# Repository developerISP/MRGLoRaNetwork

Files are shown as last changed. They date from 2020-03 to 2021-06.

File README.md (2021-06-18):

# Col Margherita LoRa Project (ROSY: Remote Observatory SYstem)
This is the repository for the school-work project between the Istitute of Polar Science ISP-CNR of Venice and the ITIS Max Planck of Villorba (TV)

# Who
The wonderful people involved in the ROSY project are all students, as they will never stop to learn! 

The young team in electronics, computer science, power management and telecommunications that built up the work is:
Nicolò Baseggio,
Davide Dal Bo,
Andrea De Marchi,
Michele Ferrarese,
Massimiliano Granziol,
Marco Martini,
Silvia Mondin,
Federico Peruzzo,
Roberto Pomiato,
Nicolò Rasera,
Nicola Voltarel

The group is trained and motivated by selfless and great teachers:
Alessandro Rocco Monteduro,
Monica Disarò,
Eugenio Rossi,
Giorgio Damian

The project is coordinated by enthusiastic researchers:
Federico Dallo,
Daniele Zannoni,
Fabrizio De Blasi,
Jacopo Gabrieli,
Carlo Barbante

# When
The project started in January 2020, continued throughout the tough Covid-19 pandemic thanks to the great motivation of the students and is on its way to be completed during the spring 2021. We were able to continue the development of hardware and software thanks to the distance learing (DAD) and tele-work. We have met at the ITIS Max Planck laboratories to build up the instrumentations and to perform several test, such as measuring the power comsumption and telecommunication capabilieties of the instruments. We were hosted at the Ca' Foscari University Campus in Via Torino and at the National Research Council (CNR) Col Margherita Observatory in the Belluno province.

# How

# Why

# Network
Files related to the acquisition, communication and ... are organized in the "network" directory. 

# Meteorology
Files for the analysis of meteorological variables are organized in the "meteorology" directory.
```
.
└── meteorology
    ├── data
    │   ├── MRG_2017_2018.csv
    │   └── P_Valles_2010_2020.csv
    ├── main.R
    └── outputs
        ├── MRGatmosphericpressuretypicalyear.csv
        ├── MRGatmosphericpressuretypicalyear.png
        ├── MRGrelativehumiditytypicalyear.csv
        ├── MRGrelativehumiditytypicalyear.png
        ├── MRGsolarradiationtypicalyear.csv
        ├── MRGsolarradiationtypicalyear.png
        ├── MRGtemperaturetypicalyear.csv
        ├── MRGtemperaturetypicalyear.png
        ├── MRGwinddirectiontypicalyear_autunno.png
        ├── MRGwinddirectiontypicalyear.csv
        ├── MRGwinddirectiontypicalyear_estate.png
        ├── MRGwinddirectiontypicalyear_inverno.png
        ├── MRGwinddirectiontypicalyear_primavera.png
        ├── MRGwindspeedtypicalyear.csv
        └── MRGwindspeedtypicalyear.png

3 directories, 18 files
```

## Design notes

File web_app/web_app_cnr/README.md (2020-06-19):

[doc]: https://dart.dev/guides/language/effective-dart/documentation

# Versione 1.0.1

## Modifiche

* è stato modificato leggermente il layout della pagina,
spostando la [timeBar](#timebar) in un "popup" accessibile cliccando il pulsante in alto a destra (con questa icona: > <)

* è stata abbozzata la documentazione dei file presenti in `MRGLoRaNetwork\web_app\web_app_cnr\lib`

## Link

vedi [Effective Dart: Documentation][doc] per maggiori informazioni sulla documentazione di dart

# Versione 1.0.2

## Modifiche

* tutti i grafici sono stati resi indipendenti l'uno dall'altro, dal punto di vista dei valori, mentre le date corrispondenti a questi sono comuni a tutti i grafici.</br>
    > ora la [timeBar](#timebar) modifica l'intervallo su tutti quanti i grafici

* sono stati completati gli `indicatori del vento e dell'umidità` *( icona e animazione)*

</br>

---

## Vocabolario

### timeBar

> Barra per la modifica dell'intervallo di tempo, visibile nei vari grafici della home page

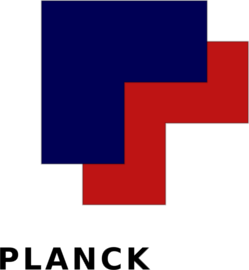
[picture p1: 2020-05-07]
web_app/web_app_cnr/images/ITIS-maxPlanck.png

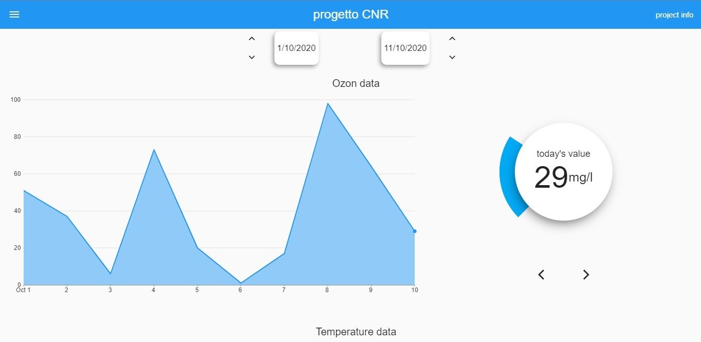
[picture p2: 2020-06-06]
web_app/web_app_cnr/images/web_app.jpg

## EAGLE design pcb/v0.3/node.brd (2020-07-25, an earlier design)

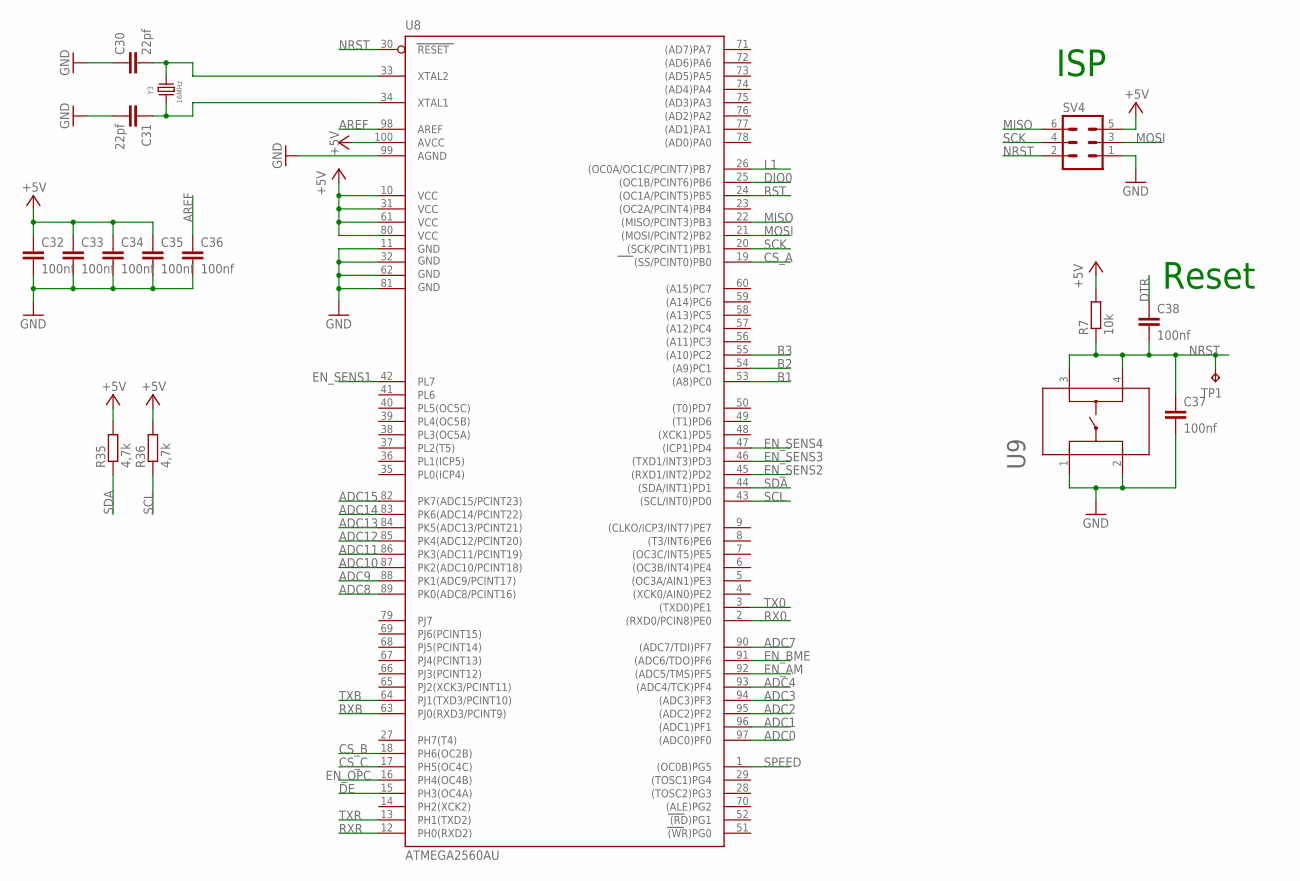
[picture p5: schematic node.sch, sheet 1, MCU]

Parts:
C30, C31: 22pf; C0603
C32, C33, C34, C35, C36, C37, C38: 100nf; C0805
R7: 10k; R0805
R35, R36: 4,7k; R0603
SV4: MA03-2
TP1: TPTP13R; TP13R
U8: ATMEGA2560AU; TQFP100
U9: 1-1825910-0; SWITCH_1-1825910-0
Y3: 16MHz; WE-XTAL_HC49/4H

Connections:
+5V: C32.1, C33.1, C34.1, C35.1, R7.2, R35.2, R36.2, SV4.5, U8.10 (VCC), U8.31 (VCC1), U8.61 (VCC2), U8.80 (VCC3), U8.100 (AVCC); also elsewhere on the board
ADC0: U8.97 ((ADC0)PF0)
ADC1: U8.96 ((ADC1)PF1); also elsewhere on the board
ADC2: U8.95 ((ADC2)PF2); also elsewhere on the board
ADC3: U8.94 ((ADC3)PF3); also elsewhere on the board
ADC4: U8.93 ((ADC4/TCK)PF4); also elsewhere on the board
ADC7: U8.90 ((ADC7/TDI)PF7); also elsewhere on the board
ADC8: U8.89 (PK0(ADC8/PCINT16))
ADC9: U8.88 (PK1(ADC9/PCINT17))
ADC10: U8.87 (PK2(ADC10/PCINT18))
ADC11: U8.86 (PK3(ADC11/PCINT19))
ADC12: U8.85 (PK4(ADC12/PCINT20))
ADC13: U8.84 (PK5(ADC13/PCINT21))
ADC14: U8.83 (PK6(ADC14/PCINT22))
ADC15: U8.82 (PK7(ADC15/PCINT23))
AREF: C36.1, U8.98 (AREF)
B1: U8.53 ((A8)PC0); also elsewhere on the board
B2: U8.54 ((A9)PC1); also elsewhere on the board
B3: U8.55 ((A10)PC2)
CS_A: U8.19 ((SS/PCINT0)PB0); also elsewhere on the board
CS_B: U8.18 (PH6(OC2B)); also elsewhere on the board
CS_C: U8.17 (PH5(OC4C)); also elsewhere on the board
DE: U8.15 (PH3(OC4A)); also elsewhere on the board
DIO0: U8.25 ((OC1B/PCINT6)PB6); also elsewhere on the board
DTR: C38.1; also elsewhere on the board
EN_AM: U8.92 ((ADC5/TMS)PF5); also elsewhere on the board
EN_BME: U8.91 ((ADC6/TDO)PF6); also elsewhere on the board
EN_OPC: U8.16 (PH4(OC4B)); also elsewhere on the board
EN_SENS1: U8.42 (PL7); also elsewhere on the board
EN_SENS2: U8.45 ((RXD1/INT2)PD2); also elsewhere on the board
EN_SENS3: U8.46 ((TXD1/INT3)PD3); also elsewhere on the board
EN_SENS4: U8.47 ((ICP1)PD4); also elsewhere on the board
GND: C30.1, C31.2, C32.2, C33.2, C34.2, C35.2, C36.2, C37.2, SV4.1, U8.11 (GND), U8.32 (GND1), U8.62 (GND2), U8.81 (GND3), U8.99 (AGND), U9.1, U9.2; also elsewhere on the board
L1: U8.26 ((OC0A/OC1C/PCINT7)PB7); also elsewhere on the board
MISO: SV4.6, U8.22 ((MISO/PCINT3)PB3); also elsewhere on the board
MOSI: SV4.3, U8.21 ((MOSI/PCINT2)PB2); also elsewhere on the board
unnamed: C30.2, U8.33 (XTAL2), Y3.2
unnamed: C31.1, U8.34 (XTAL1), Y3.1
NRST: C37.1, C38.2, R7.1, SV4.2, TP1.TP, U8.30 (RESET), U9.3, U9.4
RST: U8.24 ((OC1A/PCINT5)PB5); also elsewhere on the board
RX0: U8.2 ((RXD0/PCIN8)PE0); also elsewhere on the board
RXB: U8.63 (PJ0(RXD3/PCINT9)); also elsewhere on the board
RXR: U8.12 (PH0(RXD2)); also elsewhere on the board
SCK: SV4.4, U8.20 ((SCK/PCINT1)PB1); also elsewhere on the board
SCL: R36.1, U8.43 ((SCL/INT0)PD0); also elsewhere on the board
SDA: R35.1, U8.44 ((SDA/INT1)PD1); also elsewhere on the board
SPEED: U8.1 ((OC0B)PG5); also elsewhere on the board
TX0: U8.3 ((TXD0)PE1); also elsewhere on the board
TXB: U8.64 (PJ1(TXD3/PCINT10)); also elsewhere on the board
TXR: U8.13 (PH1(TXD2)); also elsewhere on the board

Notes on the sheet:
Reset
ISP

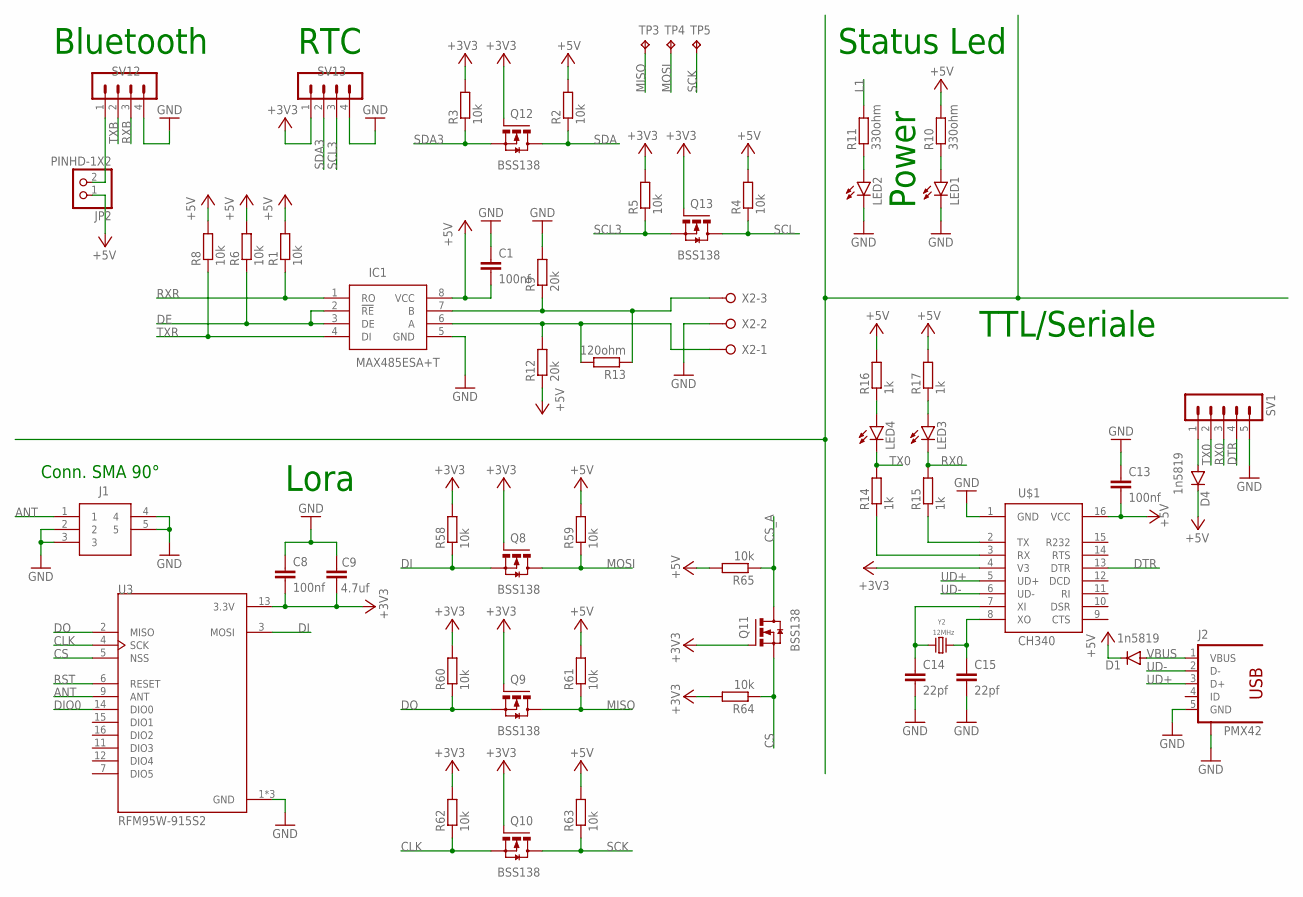
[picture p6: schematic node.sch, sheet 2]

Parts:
C1, C8, C13: 100nf; C0805
C9: 4.7uf; C1206K
C14, C15: 22pf; C0603
D1, D4: 1n5819; SOD123
IC1: MAX485ESA+T; SOIC127P600X175-8N
J1: 5-1814400-1; 518144001
J2: PMX42; PMX42_56579-0576
JP2: PINHD-1X2; 1X02
LED1, LED2, LED3, LED4: LEDSML0805; SML0805
Q8, Q9, Q10, Q11, Q12, Q13: BSS138; SOT23-3
R1, R2, R3, R4, R5, R6, R8, R58, R59, R60, R61, R62, R63, R64, R65: 10k; R0805
R9, R12: 20k; R0805
R10, R11: 330ohm; R0805
R13: 120ohm; R0805
R14, R15, R16, R17: 1k; R0805
SV1: MA05-1
SV12, SV13: MA04-1
TP3, TP4, TP5: TPTP13R; TP13R
U3: RFM95W-915S2; XCVR_RFM95W-915S2
U$1: CH340; SOIC16
X2: W237-3E
Y2: 12MHz; WE-XTAL_HC49/4H

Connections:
+3V3: C8.2, C9.1, Q8.1 (G), Q9.1 (G), Q10.1 (G), Q11.1 (G), Q12.1 (G), Q13.1 (G), R3.2, R5.2, R58.2, R60.2, R62.2, R64.2, SV13.1, U3.13 (3.3V), U$1.4 (V3); also elsewhere on the board
+5V: C1.2, C13.2, D1.C, D4.C, IC1.8 (VCC), JP2.1, R1.2, R2.2, R4.2, R6.2, R8.2, R10.2, R12.1, R16.2, R17.2, R59.2, R61.2, R63.2, R65.2, U$1.16 (VCC); also elsewhere on the board
ANT: J1.1, U3.9 (ANT)
CLK: Q10.2 (S), R62.1, U3.4 (SCK)
CS: Q11.2 (S), R64.1, U3.5 (NSS)
CS_A: Q11.3 (D), R65.1; also elsewhere on the board
DE: IC1.2 (!RE), IC1.3 (DE), R6.1; also elsewhere on the board
DI: Q8.2 (S), R58.1, U3.3 (MOSI)
DIO0: U3.14 (DIO0); also elsewhere on the board
DO: Q9.2 (S), R60.1, U3.2 (MISO)
DTR: SV1.4, U$1.13 (DTR); also elsewhere on the board
GND: C1.1, C8.1, C9.2, C13.1, C14.2, C15.2, IC1.5 (GND), J1.2, J1.3, J1.4, J1.5, J2.5 (GND), J2.S1 (S), J2.S2 (S), J2.S3 (S), J2.S4 (S), LED1.C, LED2.C, R9.2, SV1.5, SV12.4, SV13.4, U3.1 (GND), U3.8 (GND), U3.10 (GND), U$1.1 (GND), X2.2; also elsewhere on the board
L1: R11.2; also elsewhere on the board
MISO: Q9.3 (D), R61.1, TP3.TP; also elsewhere on the board
MOSI: Q8.3 (D), R59.1, TP4.TP; also elsewhere on the board
unnamed: JP2.2, SV12.1
unnamed: LED1.A, R10.1
unnamed: LED2.A, R11.1
unnamed: R15.1, U$1.2 (TX)
unnamed: R14.1, U$1.3 (RX)
unnamed: C15.1, U$1.8 (XO), Y2.1
unnamed: C14.1, U$1.7 (XI), Y2.2
unnamed: LED3.A, R17.1
unnamed: LED4.A, R16.1
unnamed: D4.A, SV1.1
unnamed: IC1.6 (A), R12.2, R13.2, X2.1
unnamed: IC1.7 (B), R9.1, R13.1, X2.3
RST: U3.6 (RESET); also elsewhere on the board
RX0: LED3.C, R15.2, SV1.3; also elsewhere on the board
RXB: SV12.3; also elsewhere on the board
RXR: IC1.1 (RO), R1.1; also elsewhere on the board
SCK: Q10.3 (D), R63.1, TP5.TP; also elsewhere on the board
SCL: Q13.3 (D), R4.1; also elsewhere on the board
SCL3: Q13.2 (S), R5.1, SV13.3
SDA: Q12.3 (D), R2.1; also elsewhere on the board
SDA3: Q12.2 (S), R3.1, SV13.2
TX0: LED4.C, R14.2, SV1.2; also elsewhere on the board
TXB: SV12.2; also elsewhere on the board
TXR: IC1.4 (DI), R8.1; also elsewhere on the board
UD+: J2.3 (D+), U$1.5 (UD+)
UD-: J2.2 (D-), U$1.6 (UD-)
VBUS: D1.A, J2.1 (VBUS)

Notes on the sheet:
Power
Lora
Conn. SMA 90°
TTL/Seriale
Status Led
Bluetooth
RTC

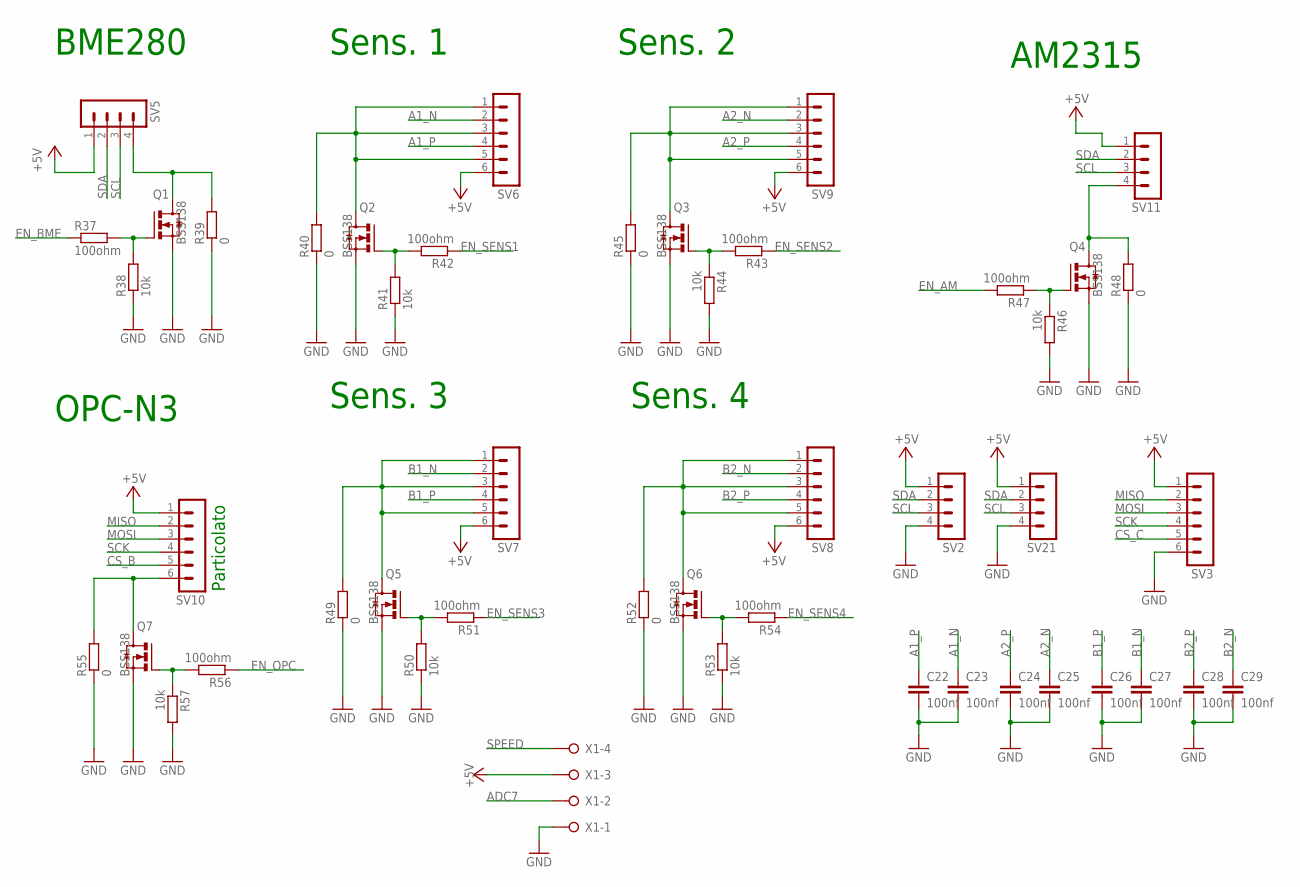
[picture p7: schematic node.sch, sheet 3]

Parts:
C22, C23, C24, C25, C26, C27, C28, C29: 100nf; C0805
Q1, Q2, Q3, Q4, Q5, Q6, Q7: BSS138; SOT23-3
R37, R42, R43, R47, R51, R54, R56: 100ohm; R0805W
R38, R41, R44, R46, R50, R53, R57: 10k; R0805W
R39, R40, R45, R48, R49, R52, R55: 0; R0603
SV2, SV5, SV11, SV21: MA04-1
SV3, SV6, SV7, SV8, SV9, SV10: MA06-1
X1: W237-04P; W237-4P

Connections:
+5V: SV2.1, SV3.1, SV5.1, SV6.6, SV7.6, SV8.6, SV9.6, SV10.1, SV11.1, SV21.1, X1.3; also elsewhere on the board
A1_N: C23.1, SV6.2; also elsewhere on the board
A1_P: C22.1, SV6.4; also elsewhere on the board
A2_N: C25.1, SV9.2; also elsewhere on the board
A2_P: C24.1, SV9.4; also elsewhere on the board
ADC7: X1.2; also elsewhere on the board
B1_N: C27.1, SV7.2; also elsewhere on the board
B1_P: C26.1, SV7.4; also elsewhere on the board
B2_N: C29.1, SV8.2; also elsewhere on the board
B2_P: C28.1, SV8.4; also elsewhere on the board
CS_B: SV10.5; also elsewhere on the board
CS_C: SV3.5; also elsewhere on the board
EN_AM: R47.2; also elsewhere on the board
EN_BME: R37.1; also elsewhere on the board
EN_OPC: R56.1; also elsewhere on the board
EN_SENS1: R42.1; also elsewhere on the board
EN_SENS2: R43.1; also elsewhere on the board
EN_SENS3: R51.1; also elsewhere on the board
EN_SENS4: R54.1; also elsewhere on the board
GND: C22.2, C23.2, C24.2, C25.2, C26.2, C27.2, C28.2, C29.2, Q1.2 (S), Q2.2 (S), Q3.2 (S), Q4.2 (S), Q5.2 (S), Q6.2 (S), Q7.2 (S), R38.1, R39.1, R40.1, R41.1, R44.2, R45.1, R46.2, R48.1, R49.1, R50.1, R52.1, R53.1, R55.1, R57.2, SV2.4, SV3.6, SV21.4, X1.1; also elsewhere on the board
MISO: SV3.2, SV10.2; also elsewhere on the board
MOSI: SV3.3, SV10.3; also elsewhere on the board
unnamed: Q1.3 (D), R39.2, SV5.4
unnamed: Q1.1 (G), R37.2, R38.2
unnamed: Q6.3 (D), R52.2, SV8.1, SV8.3, SV8.5
unnamed: Q2.3 (D), R40.2, SV6.1, SV6.3, SV6.5
unnamed: Q5.3 (D), R49.2, SV7.1, SV7.3, SV7.5
unnamed: Q2.1 (G), R41.2, R42.2
unnamed: Q4.3 (D), R48.2, SV11.4
unnamed: Q3.3 (D), R45.2, SV9.1, SV9.3, SV9.5
unnamed: Q3.1 (G), R43.2, R44.1
unnamed: Q4.1 (G), R46.1, R47.1
unnamed: Q6.1 (G), R53.2, R54.2
unnamed: Q5.1 (G), R50.2, R51.2
unnamed: Q7.3 (D), R55.2, SV10.6
unnamed: Q7.1 (G), R56.2, R57.1
SCK: SV3.4, SV10.4; also elsewhere on the board
SCL: SV2.3, SV5.3, SV11.3, SV21.3; also elsewhere on the board
SDA: SV2.2, SV5.2, SV11.2, SV21.2; also elsewhere on the board
SPEED: X1.4; also elsewhere on the board

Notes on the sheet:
OPC-N3
AM2315
Particolato
Sens. 1
Sens. 2
Sens. 3
Sens. 4
BME280

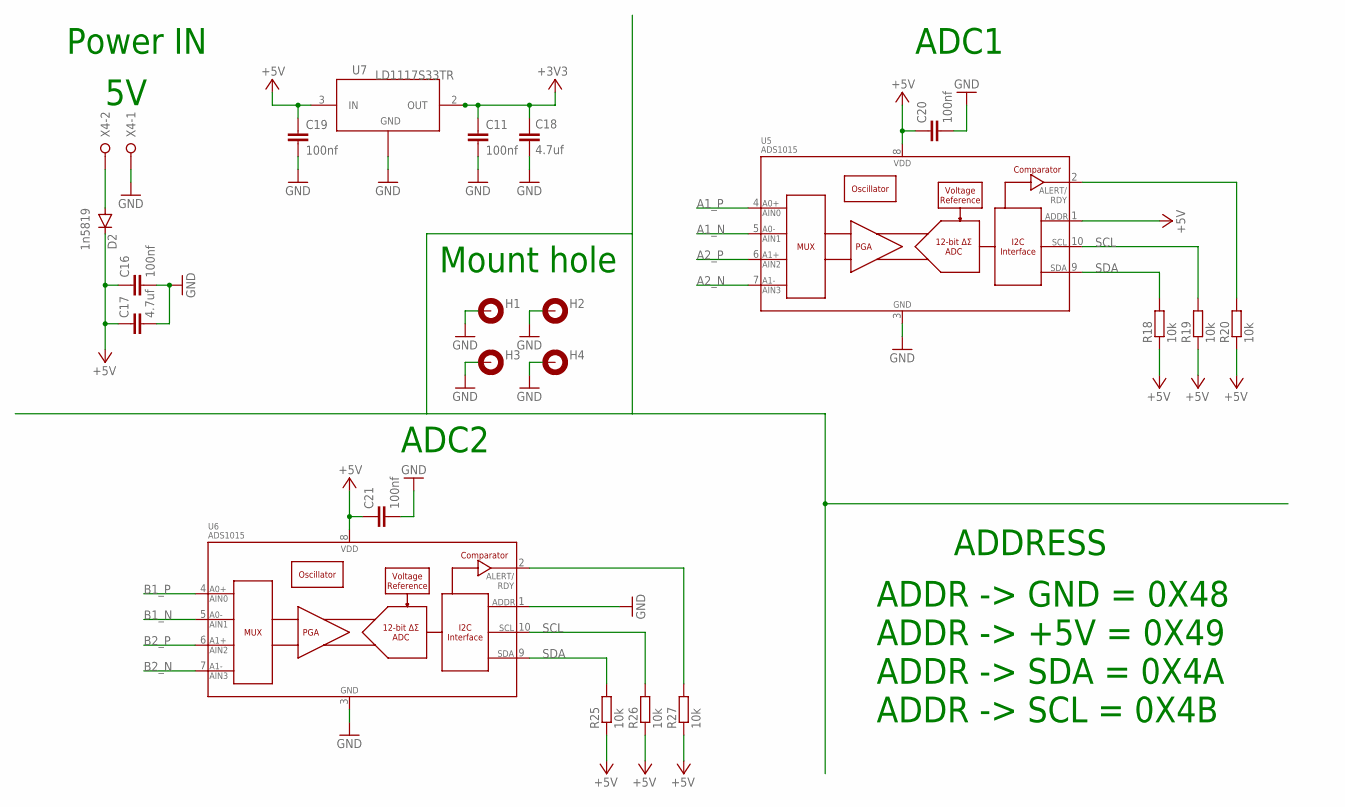
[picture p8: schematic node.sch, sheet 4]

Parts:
C11, C16, C19, C20, C21: 100nf; C0805
C17, C18: 4.7uf; C1206K
D2: 1n5819; SOD123
H1, H2, H3, H4: MOUNT-PAD-ROUND3.2; 3,2-PAD
R18, R19, R20, R25, R26, R27: 10k; R0805
U5, U6: ADS1015; MSOP10
U7: LD1117S33TR; SOT-223
X4: W237-02P; W237-132

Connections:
+3V3: C11.1, C18.1, U7.2 (OUT), U7.4; also elsewhere on the board
+5V: C16.1, C17.1, C19.1, C20.1, C21.1, D2.C, R18.1, R19.1, R20.1, R25.1, R26.1, R27.1, U5.1 (ADDR), U5.8 (VDD), U6.8 (VDD), U7.3 (IN); also elsewhere on the board
A1_N: U5.5 (AIN1); also elsewhere on the board
A1_P: U5.4 (AIN0); also elsewhere on the board
A2_N: U5.7 (AIN3); also elsewhere on the board
A2_P: U5.6 (AIN2); also elsewhere on the board
B1_N: U6.5 (AIN1); also elsewhere on the board
B1_P: U6.4 (AIN0); also elsewhere on the board
B2_N: U6.7 (AIN3); also elsewhere on the board
B2_P: U6.6 (AIN2); also elsewhere on the board
GND: C11.2, C16.2, C17.2, C18.2, C19.2, C20.2, C21.2, H1.B3,2, H2.B3,2, H3.B3,2, H4.B3,2, U5.3 (VSS), U6.1 (ADDR), U6.3 (VSS), U7.1 (ADJ/GND), X4.1; also elsewhere on the board
unnamed: D2.A, X4.2
unnamed: R20.2, U5.2 (ALERT/RDY)
unnamed: R27.2, U6.2 (ALERT/RDY)
SCL: R19.2, R26.2, U5.10 (SCL), U6.10 (SCL); also elsewhere on the board
SDA: R18.2, R25.2, U5.9 (SDA), U6.9 (SDA); also elsewhere on the board

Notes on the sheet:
ADC2
ADC1
ADDRESS
ADDR -> +5V = 0X49
ADDR -> GND = 0X48
ADDR -> SDA = 0X4A
ADDR -> SCL = 0X4B
Power IN
Mount hole

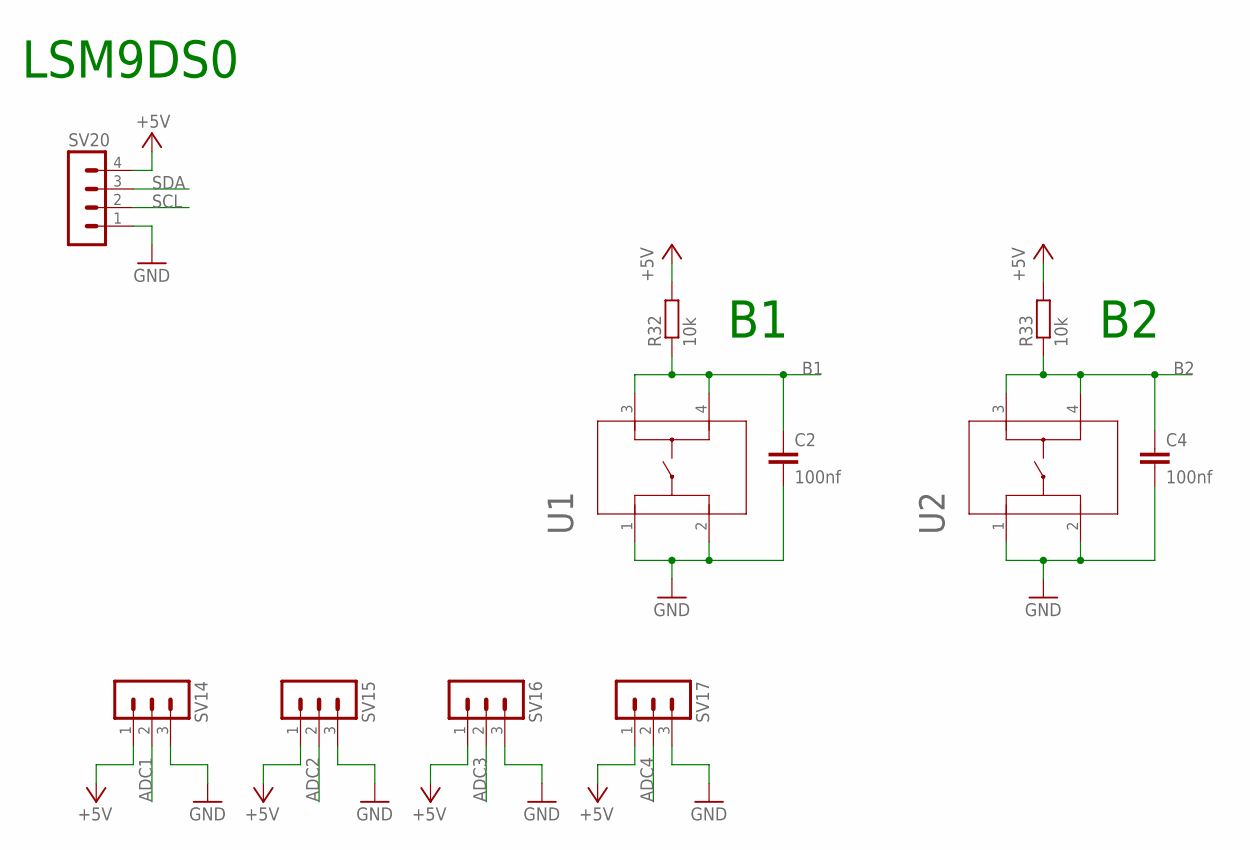
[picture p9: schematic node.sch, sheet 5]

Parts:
C2, C4: 100nf; C0805
R32, R33: 10k; R0805
SV14, SV15, SV16, SV17: MA03-1
SV20: MA04-1
U1, U2: 1-1825910-0; SWITCH_1-1825910-0

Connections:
+5V: R32.2, R33.2, SV14.1, SV15.1, SV16.1, SV17.1, SV20.4; also elsewhere on the board
ADC1: SV14.2; also elsewhere on the board
ADC2: SV15.2; also elsewhere on the board
ADC3: SV16.2; also elsewhere on the board
ADC4: SV17.2; also elsewhere on the board
B1: C2.1, R32.1, U1.3, U1.4; also elsewhere on the board
B2: C4.1, R33.1, U2.3, U2.4; also elsewhere on the board
GND: C2.2, C4.2, SV14.3, SV15.3, SV16.3, SV17.3, SV20.1, U1.1, U1.2, U2.1, U2.2; also elsewhere on the board
SCL: SV20.2; also elsewhere on the board
SDA: SV20.3; also elsewhere on the board

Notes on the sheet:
LSM9DS0

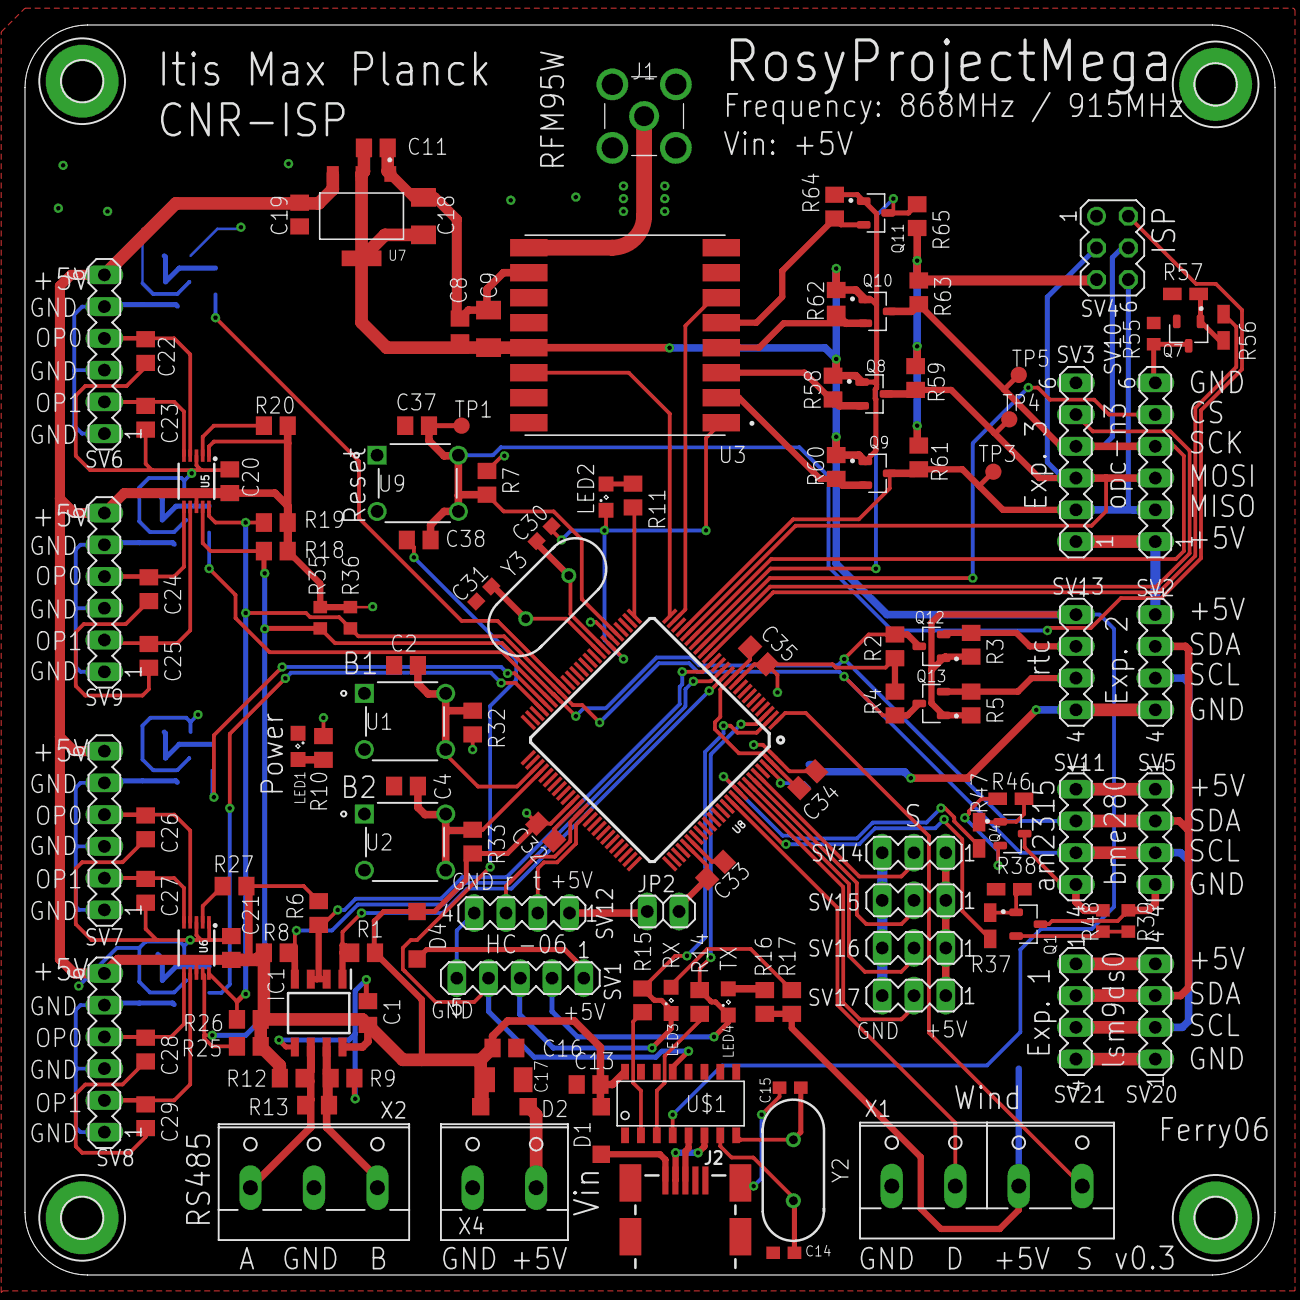
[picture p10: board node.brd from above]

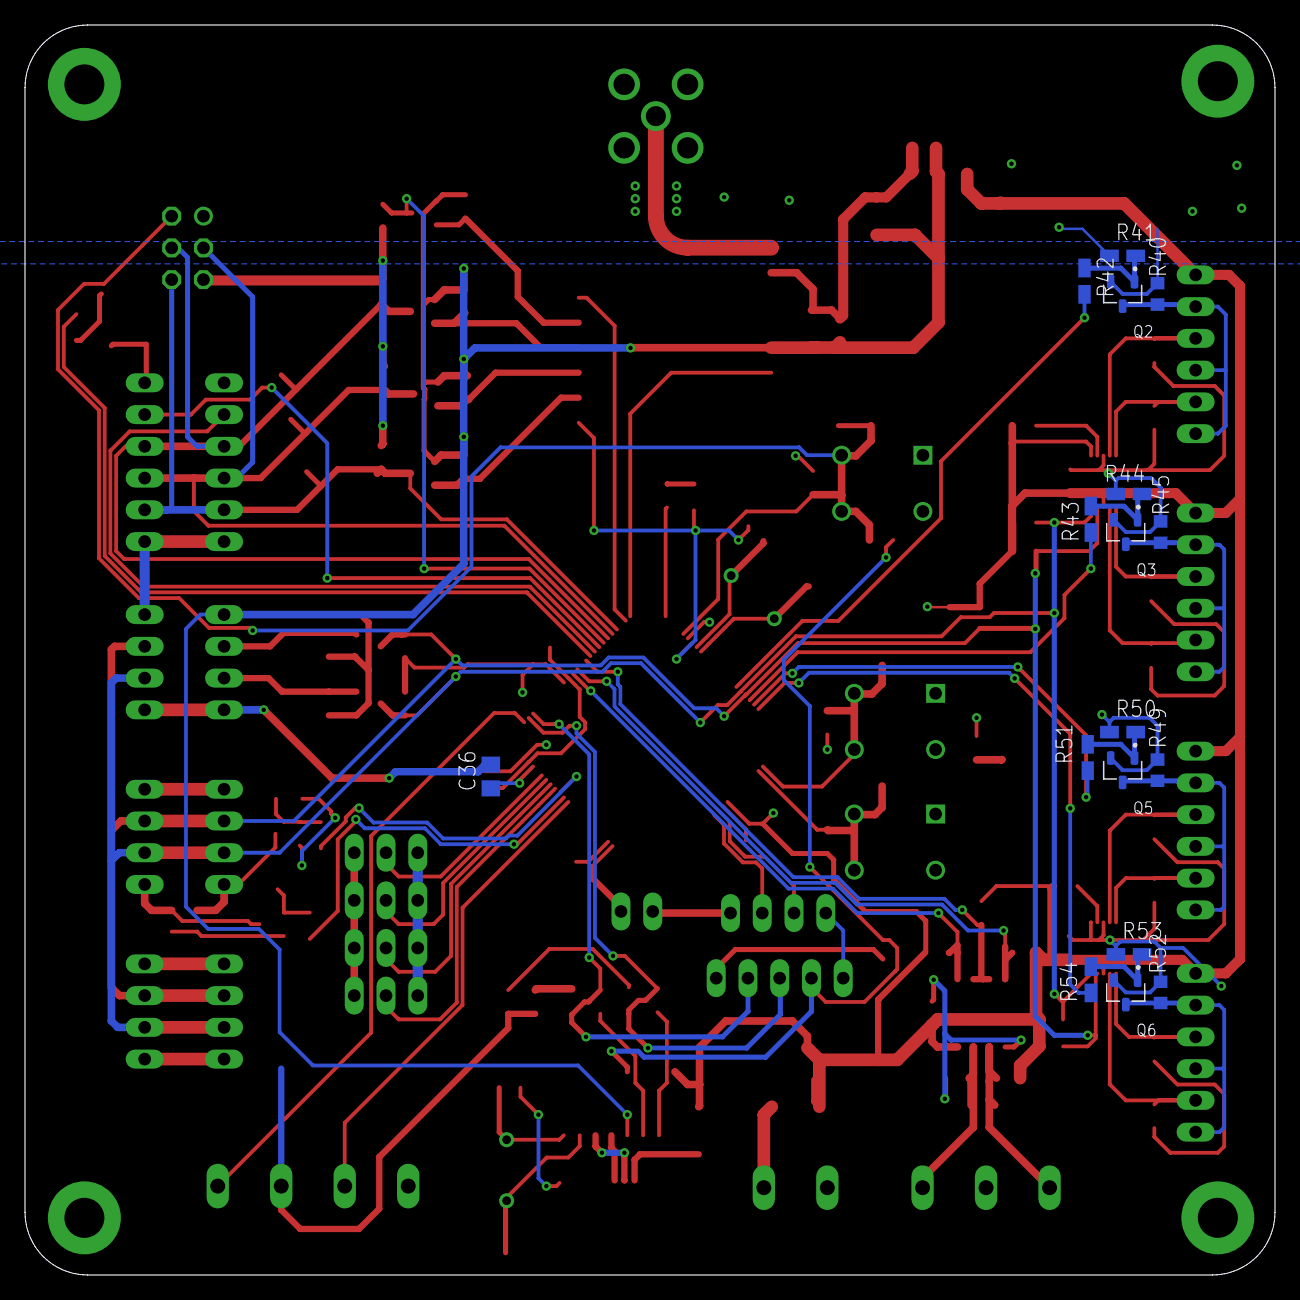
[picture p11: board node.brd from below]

Board: 2 copper layers, 100.0 x 100.0 mm, 153 parts (17 on the bottom side), 88 nets.

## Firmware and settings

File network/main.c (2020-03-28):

/**
  ******************************************************************************
  * @file    main.c
  * @author  MCD Application Team
  * @brief   Main program body
  ******************************************************************************
  * @attention
  *
  * <h2><center>&copy; Copyright (c) 2018 STMicroelectronics.
  * All rights reserved.</center></h2>
  *
  * This software component is licensed by ST under Ultimate Liberty license
  * SLA0044, the "License"; You may not use this file except in compliance with
  * the License. You may obtain a copy of the License at:
  *                             www.st.com/SLA0044
  *
  ******************************************************************************
  */

/* Includes ------------------------------------------------------------------*/
#include "hw.h"
#include "low_power_manager.h"
#include "bsp.h"
#include "timeServer.h"
#include <string.h>
#include <stdlib.h>

#include "stm32l0xx_hal.h"
#include "lora_driver.h"
#include <stdarg.h>

#include ATCMD_MODEM        /* preprocessing definition in hw_conf.h*/



/* Private typedef -----------------------------------------------------------*/

/* Private define ------------------------------------------------------------*/

/* CAYENNE_LLP is myDevices Application server*/
#define CAYENNE_LPP
#define LPP_DATATYPE_DIGITAL_INPUT 0x0
#define LPP_DATATYPE_DIGITAL_OUTPUT 0x1
#define LPP_DATATYPE_HUMIDITY 0x68
#define LPP_DATATYPE_TEMPERATURE 0x67
#define LPP_DATATYPE_BAROMETER 0x73

/* Private variables ---------------------------------------------------------*/

/* Private variables ---------------------------------------------------------*/

static sensor_t Sensor;                            /* struct for data sensor*/

#if USE_LRWAN_NS1
static bool user_button_flag = true;
#endif


/* Private function prototypes -----------------------------------------------*/

static void SensorMeasureData(sSendDataBinary_t *SendDataBinary);

/* load call backs*/
static LoRaDriverCallback_t LoRaDriverCallbacks = { SensorMeasureData,
                                                    NULL
                                                  };

#if USE_LRWAN_NS1
/**
 * @brief  EXTI line detection callbacks.
 * @param  GPIO_Pin: Specifies the pins connected to the EXTI line.
 * @retval None
 */
void HAL_GPIO_EXTI_Callback(uint16_t GPIO_Pin)
{
  HW_RTC_DelayMs(10);
  if (!HW_GPIO_Read(USER_BUTTON_GPIO_PORT, USER_BUTTON_PIN))
  {
    if (user_button_flag)
    {
      Modem_IO_DeInit();
      BSP_LED_DeInit(LED2);
      user_button_flag = false;
      while (1);
    }
    else
    {
      Modem_IO_Init();
      NVIC_SystemReset();
    }
  }
}
#endif

/* Private macro ------------- -----------------------------------------------*/

#ifdef CAYENNE_LPP
#define LORAWAN_APP_PORT           99;            /*LoRaWAN application port*/
#else
#define LORAWAN_APP_PORT           2;            /*LoRaWAN application port*/
#endif

#define LORAWAN_CONFIRMED_MSG      ENABLE         /*LoRaWAN confirmed messages*/

#define SENSORS_MEASURE_CYCLE      15000          /*Periode to do sensors measurement*/

#define JOIN_MODE                  OTAA_JOIN_MODE   /*ABP_JOIN_MODE */ /*LoRaWan join methode*/

#ifdef USE_LRWAN_NS1
#define FREQ_BAND                 EU868 //CN470PREQUEL
#endif


/* Init LoRa Driver modem parameters*/
#ifdef USE_LRWAN_NS1
static LoRaDriverParam_t LoRaDriverParam = {  SENSORS_MEASURE_CYCLE,  JOIN_MODE, FREQ_BAND};
#else
static LoRaDriverParam_t LoRaDriverParam = {  SENSORS_MEASURE_CYCLE,  JOIN_MODE};
#endif

/**
 * @brief  Entry point program
 * @param  None
 * @retval int
 */
int main(void)
{


  /* MCU Configuration----------------------------------------------------------*/

  /* Reset of all peripherals, Initializes the Flash interface and the Systick. */
  HAL_Init();

  /* Configure the system clock */
  SystemClock_Config();

  /* Initialize all configured peripherals */
  HW_GpioInit();

  /* Configure the debug mode*/
#if 0
  DBG_Init();
#endif

  /* Configure the hardware*/
  HW_Init();

  /*Disable standby mode*/
  LPM_SetOffMode(LPM_APPLI_Id, LPM_Disable);

  /* Context Initialization following the LoRa device modem Used*/
  Lora_Ctx_Init(&LoRaDriverCallbacks, &LoRaDriverParam);

  DBG_PRINTF("before idle \n");

  /* Infinite loop */
  while (1)
  {

    //macchina a stati 
    Lora_fsm(); //riga 1831 del file lora_driver.c
    DISABLE_IRQ();
    /* if an interrupt has occurred after DISABLE_IRQ, it is kept pending
     * and cortex will not enter low power anyway  */
    if ((lora_getDeviceState() == DEVICE_SLEEP) && (HW_UART_Modem_IsNewCharReceived() == RESET))
    {
#ifndef LOW_POWER_DISABLE
      LPM_EnterLowPower();
#endif
    }
    ENABLE_IRQ();

  }
}



/********************* LoRa Part Apllication **********************************/

/******************************************************************************
 * @brief SensorMeasureData
 * @param none
 * @return none
******************************************************************************/
static void SensorMeasureData(sSendDataBinary_t *SendDataBinary)
{
  uint8_t LedState = 0;                /*just for padding*/
  uint16_t pressure = 0;
  int16_t temperature = 0;
  uint16_t humidity = 0;
  uint32_t BatLevel = 0;                /*end device connected to external power source*/
  uint8_t index = 0;
  ATEerror_t LoraCmdRetCode;

  /*read pressure, Humidity and Temperature in order to be send on LoRaWAN*/
  BSP_sensor_Read(&Sensor);

#ifdef CAYENNE_LPP
  uint8_t cchannel = 0;

  temperature = (int16_t)(Sensor.temperature * 10);         /* in °C * 10 */
  pressure    = (uint16_t)(Sensor.pressure * 100 / 10);      /* in hPa / 10 */
  humidity    = (uint16_t)(Sensor.humidity * 2);            /* in %*2     */

#ifdef USE_LRWAN_NS1
  uint8_t str_buff[100];
  memset(str_buff, 0, sizeof(str_buff));
  sprintf((char *)str_buff, "Pressure: %.1f hPa   Temperature: %.1f degreeC   Humidity: %.1f\r\n", Sensor.pressure, \
          Sensor.temperature, \
          Sensor.humidity);
#if defined CMD_DEBUG
  at_printf_send(str_buff, strlen((const char *)str_buff));
#endif

#endif

  SendDataBinary->Buffer[index++] = cchannel++;
  SendDataBinary->Buffer[index++] = LPP_DATATYPE_BAROMETER;
  SendDataBinary->Buffer[index++] = (pressure >> 8) & 0xFF;
  SendDataBinary->Buffer[index++] = pressure & 0xFF;
  SendDataBinary->Buffer[index++] = cchannel++;
  SendDataBinary->Buffer[index++] = LPP_DATATYPE_TEMPERATURE;
  SendDataBinary->Buffer[index++] = (temperature >> 8) & 0xFF;
  SendDataBinary->Buffer[index++] = temperature & 0xFF;
  SendDataBinary->Buffer[index++] = cchannel++;
  SendDataBinary->Buffer[index++] = LPP_DATATYPE_HUMIDITY;
  SendDataBinary->Buffer[index++] = humidity & 0xFF;
  SendDataBinary->Buffer[index++] = cchannel++;
  SendDataBinary->Buffer[index++] = LPP_DATATYPE_DIGITAL_INPUT;

  /*get battery level of the modem (slave)*/
  LoraCmdRetCode = Lora_GetBatLevel(&BatLevel);
#ifdef USE_LRWAN_NS1
  if (LoraCmdRetCode == ATCTL_RET_CMD_VDD)
#else
  if (LoraCmdRetCode == AT_OK)
#endif
  {
    DBG_PRINTF("Msg status = %d --> OK\n", (uint16_t)BatLevel);
  }
  else
  {
    DBG_PRINTF("Msg status = %d --> KO\n", (uint16_t)BatLevel);
  }

  SendDataBinary->Buffer[index++] = BatLevel * 100 / 254;
  SendDataBinary->Buffer[index++] = cchannel++;
  SendDataBinary->Buffer[index++] = LPP_DATATYPE_DIGITAL_OUTPUT;
  SendDataBinary->Buffer[index++] = LedState;

#else

  int32_t latitude, longitude = 0;     /*just for padding*/
  uint16_t altitudeGps = 0;            /*just for padding*/

  temperature = (int16_t)(Sensor.temperature * 100);         /* in °C * 100 */
  pressure    = (uint16_t)(Sensor.pressure * 100 / 10);      /* in hPa / 10 */
  humidity    = (uint16_t)(Sensor.humidity * 10);            /* in %*10     */

  latitude = Sensor.latitude;    /* not relevant*/
  longitude = Sensor.longitude;  /* not relevant*/

  /*fill up the send buffer*/
  SendDataBinary->Buffer[index++] = LedState;
  SendDataBinary->Buffer[index++] = (pressure >> 8) & 0xFF;
  SendDataBinary->Buffer[index++] =  pressure & 0xFF;
  SendDataBinary->Buffer[index++] = (temperature >> 8) & 0xFF;
  SendDataBinary->Buffer[index++] =  temperature & 0xFF;
  SendDataBinary->Buffer[index++] = (humidity >> 8) & 0xFF;
  SendDataBinary->Buffer[index++] =  humidity & 0xFF;

  /*get battery level of the modem (slave)*/
  LoraCmdRetCode = Lora_GetBatLevel(&BatLevel);
  if (LoraCmdRetCode == AT_OK)
  {
    DBG_PRINTF("Msg status = %d --> OK\n", BatLevel);
  }
  else
  {
    DBG_PRINTF("Msg status = %d --> KO\n", BatLevel);
  }
  SendDataBinary->Buffer[index++] = (uint8_t)BatLevel;

  /*remaining data just for padding*/
  SendDataBinary->Buffer[index++] = (latitude >> 16) & 0xFF;
  SendDataBinary->Buffer[index++] = (latitude >> 8) & 0xFF;
  SendDataBinary->Buffer[index++] = latitude & 0xFF;
  SendDataBinary->Buffer[index++] = (longitude >> 16) & 0xFF;
  SendDataBinary->Buffer[index++] = (longitude >> 8) & 0xFF;
  SendDataBinary->Buffer[index++] = longitude & 0xFF;
  SendDataBinary->Buffer[index++] = (altitudeGps >> 8) & 0xFF;
  SendDataBinary->Buffer[index++] = altitudeGps & 0xFF;

#endif  /*CAYENNE_LPP*/

  SendDataBinary->DataSize = index;
#ifndef USE_LRWAN_NS1
  SendDataBinary->Port = LORAWAN_APP_PORT;
#endif

#ifdef USE_I_NUCLEO_LRWAN1
  SendDataBinary->Ack = !LORAWAN_CONFIRMED_MSG;
#endif
}

#ifdef USE_FULL_ASSERT

/**
   * @brief Reports the name of the source file and the source line number
   * where the assert_param error has occurred.
   * @param file: pointer to the source file name
   * @param line: assert_param error line source number
   * @retval None
   */
void assert_failed(uint8_t *file, uint32_t line)
{

  /* User can add his own implementation to report the file name and line number,
    ex: printf("Wrong parameters value: file %s on line %d\r\n", file, line) */

}

#endif

/**
  * @}
  */

/************************ (C) COPYRIGHT STMicroelectronics *****END OF FILE****/

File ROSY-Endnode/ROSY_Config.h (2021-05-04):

#ifndef _ROSY_STATUS_H_
#define _ROSY_STATUS_H_

#define DIM_PKT_ADDR 1
#define DIM_PKT_TYPE 1
#define DIM_PKT_STATUS 9
#define DIM_PKT_TIME 4
#define DIM_PKT_TEMPERATURE (2*4)
#define DIM_PKT_HUMIDITY (2*4)
#define DIM_PKT_PRESSURE (2*2)
#define DIM_PKT_PM (2*6)
#define DIM_PKT_OZONE (2*16)
#define DIM_PKT_ACCEL (2*6)
#define DIM_PKT_MAG (2*6)
#define DIM_PKT_GYRO (2*6)
#define DIM_PKT_WINDRAIN (2*6)

#define ADDR_START 3
#define ADDR_STOP 192
#define ADDR_TRUNC 12
#define ADDR_NULL 48 

#define EEPROM_RAM false
#define EEPROM_I2C_ADDRESS 0x50
#define EEPROM_TIME_WRITE 20
#define EEPROM_TIME_READ 10
#define EEPROM_MAX_FAILED_READ 5
#define EEPROM_MAX_FAILED_WRITE 5

#define __EEPROM_LENGTH__ 32768

#define LET_PER_READ 1
#define LOG_PER_READ 30
#define INF_PER_READ 1

#define DIM_EEPROM_BUFF (DIM_PKT_TIME + DIM_PKT_TEMPERATURE + DIM_PKT_HUMIDITY + DIM_PKT_PRESSURE + DIM_PKT_PM+DIM_PKT_OZONE + DIM_PKT_ACCEL + DIM_PKT_MAG + DIM_PKT_GYRO + DIM_PKT_WINDRAIN + 1) 
#define DIM_EEPROM_INF 13 
#define DIM_EEPROM_LOG 6 

#define WEIGHT_LET (LET_PER_READ / (float)(LET_PER_READ + INF_PER_READ + LOG_PER_READ))
#define QUEUE_EEPROM_TOT_DATA (((int)(__EEPROM_LENGTH__ * WEIGHT_LET)/ DIM_EEPROM_BUFF ))
#define FREE_SPACE_AFTER_LET (__EEPROM_LENGTH__ - QUEUE_EEPROM_TOT_DATA * DIM_EEPROM_BUFF)

#define WEIGHT_INF (INF_PER_READ/ (float)(INF_PER_READ + LOG_PER_READ))
#define INF_EEPROM_TOT_DATA ((int)((int)(FREE_SPACE_AFTER_LET * WEIGHT_INF) / (int)DIM_EEPROM_INF ))
#define FREE_SPACE_AFTER_LOG (FREE_SPACE_AFTER_LET - INF_EEPROM_TOT_DATA * DIM_EEPROM_INF)

#define WEIGHT_LOG (LOG_PER_READ / (float)LOG_PER_READ)
#define LOG_EEPROM_TOT_DATA ((int)((int)(FREE_SPACE_AFTER_LOG * WEIGHT_LOG) / (int)DIM_EEPROM_LOG ))
#define FREE_SPACE_AFTER_INF (FREE_SPACE_AFTER_LOG - LOG_EEPROM_TOT_DATA * DIM_EEPROM_LOG)

#define QUEUE_EEPROM_OFFSET 0
#define INF_EEPROM_OFFSET (DIM_EEPROM_BUFF*QUEUE_EEPROM_TOT_DATA)
#define LOG_EEPROM_OFFSET (DIM_EEPROM_BUFF*QUEUE_EEPROM_TOT_DATA+DIM_EEPROM_INF*INF_EEPROM_TOT_DATA)

#define LOGACT_start_system                     0
#define LOGACT_setup_system_done                (LOGACT_start_system + 1)
#define LOGACT_update                           (LOGACT_setup_system_done + 1)

#define LOGACT_serial_on                       10
#define LOGACT_serial_off                      (LOGACT_serial_on + 1 )

#define LOGACT_start_sleep                     20     
#define LOGACT_stop_sleep                      (LOGACT_start_sleep+ 1)
#define LOGACT_sensor_on                       (LOGACT_stop_sleep+ 1)
#define LOGACT_sensor_off                      (LOGACT_sensor_on + 1)

#define LOGACT_lora_rx                         30    
#define LOGACT_lora_tx                         (LOGACT_lora_rx + 1)   
#define LOGACT_lora_ack                        (LOGACT_lora_tx + 1)
#define LOGACT_lora_rqst                       (LOGACT_lora_ack + 1)
#define LOGACT_lora_let1                       (LOGACT_lora_rqst + 1)    
#define LOGACT_lora_let2                       (LOGACT_lora_let1 + 1)   
#define LOGACT_lora_let3                       (LOGACT_lora_let2 + 1) 
#define LOGACT_lora_more_data                  (LOGACT_lora_let3 + 1)     

#define LOGACT_init_AM2315                     40
#define LOGACT_init_BME280                     (LOGACT_init_AM2315+1)
#define LOGACT_init_OPCN3                      (LOGACT_init_BME280+1)  
#define LOGACT_init_ADS1115_1                  (LOGACT_init_OPCN3+1)
#define LOGACT_init_ADS1115_2                  (LOGACT_init_ADS1115_1+1)
#define LOGACT_init_ADS1115_3                  (LOGACT_init_ADS1115_2+1)
#define LOGACT_init_DS3231                     (LOGACT_init_ADS1115_3+1)
#define LOGACT_init_Sen0186                    (LOGACT_init_DS3231+1)
#define LOGACT_init_LSM9DS0                    (LOGACT_init_Sen0186+1)
#define LOGACT_init_INA219                     (LOGACT_init_LSM9DS0+1)
#define LOGACT_init_LoRa                       (LOGACT_init_INA219+1)

#define LOGACT_eeprom_buff_app                 60
#define LOGACT_eeprom_buff_del                 (LOGACT_eeprom_buff_app+1)
#define LOGACT_eeprom_buff_get                 (LOGACT_eeprom_buff_del+1)

#define LOGACT_eeprom_log_get                  (LOGACT_eeprom_buff_get+1)

#define LOGACT_eeprom_inf_app                  (LOGACT_eeprom_log_get+1)
#define LOGACT_eeprom_inf_get                  (LOGACT_eeprom_inf_app+1)
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

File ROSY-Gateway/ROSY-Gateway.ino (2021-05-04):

#define GATEWAY_ID 12
#define ENDNODE_MAX_PER_GATEWAY 10

#include "ROSY_Config.h"
#include "ControlUnitConfig.h"
#include "Compressor.h"
#include "SendDecompressedPacket.h"
#include "ROSY_LoRa.h"
#include "Rtclib.h"

#define ENABLE_DEBUG_MODE true
#define ENABLE_PACKET_DEBUG true 
#define ENABLE_INPUT_ID false
#define ENABLE_INPUT_DATETIME false

bool isRCV = false;
bool moreData = false;
unsigned long StartTime = 0;
unsigned long start = 0;
uint8_t *ADDRESSES=0;
uint32_t datetime = 0;
DateTime dt(0,0,0,0,0,0); 

void rcvCallback()
{
	isRCV = true;
#if ENABLE_DEBUG_MODE
	Serial.println("Packet Received");
#endif
#if ENABLE_PACKET_DEBUG
	for(auto a: ROSY_Lora_Gat::buffer) Serial.print(String(a) + "  ");
	Serial.println();
#endif
	ROSY::_send_decompressed_packet(ROSY_Lora_Gat::buffer);
	moreData = ((ROSY_Lora_Gat::buffer[1] & INF_MORE_DATA) == INF_MORE_DATA) ? true : false; 
#if ENABLE_PACKET_DEBUG
	if(moreData) Serial.println("MORE DATA Request");
#endif
	ROSY_Lora_Gat::sendACK(false);
	_delay_ms(LoRa_time_ACK);
	ROSY_Lora_Gat::sendACK(true);
}


int main()
{
	init();
	Serial.begin(9600);
	ROSY_Lora_Gat::LoRaInit(53, 11, 18, rcvCallback);
#if ENABLE_DEBUG_MODE
	Serial.println("Gateway begin successful");
#endif
	StartTime = millis();
	uint8_t number_ID = 0;
	for (;;)
	{
		_delay_ms(10000);
		
		bool isEnd = false;
		String temp = "";
#if ENABLE_INPUT_ID
		start = millis();
		bool isEndIdRequest = false;
		while(!isEndIdRequest)
		{
			if ((start > millis()) ?( millis() + (pow(2, 32) - 1) - start) : (millis() - start) > 10 * 10000) 
			{
				#if ENABLE_DEBUG_MODE
				Serial.println("Serial timeout ");
				#endif
				isEndIdRequest = true;
			}
			else
			{
				while(!Serial.available())
				{
					if ((start > millis()) ? (millis() + (pow(2, 32) - 1) - start) : (millis() - start) > 10 * 1000) 
					{
						#if ENABLE_DEBUG_MODE
						Serial.println("Serial timeout (not available)");
						#endif
						break;
					}
					else
					{
						Serial.println("Request ID " + String(GATEWAY_ID));
						delay(1000);
					}	
				}
				
				while(Serial.available())
				{
					if ((start > millis()) ?( millis() + (pow(2, 32) - 1) - start) :( millis() - start) > 10 * 1000) 
					{
						#if ENABLE_DEBUG_MODE
						Serial.println("Serial timeout");
						#endif
						break;
					}
					if (Serial.readStringUntil(',') == "ID" && Serial.readStringUntil(',') == String(GATEWAY_ID))
					{
						uint8_t number = (uint8_t) Serial.readStringUntil(',').toInt();
						if(number > ENDNODE_MAX_PER_GATEWAY || number <= 0) break;
						String stringID  = Serial.readStringUntil('\n');
						int counter = 0;
						for (int i = 0; i < stringID.length(); i++) if (stringID.charAt(i) == ',') ++counter;
						if(counter == number)
						{
							number_ID = number;
							delete[] ADDRESSES;
							ADDRESSES = new uint8_t[number];
							for(int i = 0; i < number; i++)
							{
								ADDRESSES[i] = (uint8_t) stringID.substring(0, stringID.indexOf(',')).toInt();
								stringID.replace( stringID.substring( 0, stringID.indexOf(',') + 1 ), "" );
							}
							isEndIdRequest = true;
							Serial.println("ack");
						}
						#if ENABLE_DEBUG_MODE
						else Serial.println("Wrong number ID");
						#endif
					}
				}	
			}
		}
#else 
		number_ID = 1;
		delete[] ADDRESSES;
		ADDRESSES = new uint8_t[number_ID] { 1};
#endif
		if ((StartTime > millis()) ? (millis() + (pow(2, 32) - 1) - StartTime) : (millis() - StartTime) > 10 * 1000)
		{
			StartTime = millis();
			
			for(int i = 0; i < number_ID; i++)
			{
				uint8_t CUaddress = ADDRESSES[i];
			#if ENABLE_DEBUG_MODE
				Serial.println("Endnode ID-> " + String(CUaddress));
			#endif
				moreData = true;
				for (uint8_t j = 0; (j < 3) && moreData; j++) 
				{
					moreData = false;
					isRCV = false;
					for (uint8_t i = 0; (i < 3) && !isRCV; i++)
					{
					#if ENABLE_DEBUG_MODE
						Serial.println("Request type MoreData: " + ( moreData ? String("True") : String("False")));
					#endif
						isRCV = false;
						moreData = false;
					#if ENABLE_DEBUG_MODE
						Serial.println("Request starting to Endnode ID: " + String(CUaddress));
					#endif
						bool isEnd1 = false;
						start = millis();
#if ENABLE_INPUT_DATETIME
						Serial.println("Request DateTime " + String(GATEWAY_ID));
						bool isEndDateTimeRequest = false;
						while(!isEndDateTimeRequest)
						{
							if ((start > millis()) ? (millis() + (pow(2, 32) - 1 - start)) : (millis() - start) > 10 * 1000) 
							{
								#if ENABLE_DEBUG_MODE
								Serial.println("Serial timeout");
								#endif
								isEndDateTimeRequest = true;
							}
							else
							{
								while(!Serial.available())
								{
									if ((start > millis()) ? (millis() + (pow(2, 32) - 1) - start) : (millis() - start) > 10 * 1000) 
									{
										#if ENABLE_DEBUG_MODE
										Serial.println("attesa troppo lunga");
										#endif
										break;
									}
									else
									{
										Serial.println("Request DateTime " + String(GATEWAY_ID));
										delay(1000);
									}	
								}
								
								while(Serial.available())
								{
									if ((start > millis()) ? (millis() + (pow(2, 32) - 1) - start) : (millis() - start) > 10 * 1000) 
									{
										#if ENABLE_DEBUG_MODE
										Serial.println("dati non corretti");
										#endif
										break;
									}
									if (Serial.readStringUntil(',') == "DateTime" && Serial.readStringUntil(',') == String(GATEWAY_ID))
									{
										datetime = Serial.readStringUntil('\n').toInt();
										isEnd1 = true;
										Serial.println("ack");
									}
									else 
									{
										datetime = NULL;
									}
								}	
							}
						}
#else 
						datetime = NULL;
#endif
						ROSY_Lora_Gat::requestData(CUaddress, datetime);
					#if ENABLE_DEBUG_MODE
						Serial.println("Request done to Endnode ID: " + String(CUaddress));
					#endif
						while (!ROSY_Lora_Gat::failedRQST() && !isRCV) _delay_ms(LoRa_time_RQST / 100);
					}
					if (!isRCV) Serial.println("error with " + String(CUaddress) + " code: " + String(NULL));
					if(moreData) _delay_ms(LoRa_time_MORE_DATA*1000);
				}
				_delay_ms(LoRa_time_NEXT_RQST * 1000);
			}
		}
	}
}

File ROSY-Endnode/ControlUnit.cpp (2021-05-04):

#include "ControlUnit.h"

void ControlUnit::ControlUnitInit(bool(*updateCB)(), void(*loggerCallback)(uint8_t)) 
{
#if ENABLE_BME280
	this->enableBME280 = true;
#endif
#if ENABLE_AM2315
	this->enableAM2315 = true;
#endif
#if ENABLE_OPCN3
	this->enableOPC = true;
#endif
#if ENABLE_SENSOR_1 || ENABLE_SENSOR_2
	this->enableADS1115_1 = true;
#endif
#if ENABLE_SENSOR_3 || ENABLE_SENSOR_4
	this->enableADS1115_2 = true;
#endif
#if ENABLE_SENSOR_5 || ENABLE_SENSOR_6
	this->enableADS1115_3 = true;
#endif
#if ENABLE_LSM9DS0
	this->enableLSM9DS0 = true;
#endif
#if ENABLE_DS3231
	this->enableDS3231 = true;
#endif
#if ENABLE_INA219
	this->enableINA219 = true;
#endif
#if ENABLE_SEN0186
	this->enableSen0186 = true;
#endif

	this->logger = loggerCallback;
	this->initDS3231();
	this->BME280Init();
	this->AM2315Init();
	this->OPCN3Init();
	this->initADS1115_1();
	this->initADS1115_2();
	this->initADS1115_3();
	this->initLSM9DS0();
	this->INA219Init();
	this->initSen0186();
	this->update = updateCB;


#if ENABLE_DEBUG_MODE && ENABLE_I2CSCANNER
	ROSY_i2cScanner::scanner();
#endif 
#if ENABLE_DEBUG_MODE
	Serial.println("SENSOR ENABLE LIST: ");
#if !(ENABLE_AM2315 || ENABLE_BME280 || ENABLE_OPCN3 || ENABLE_SENSOR_1 || ENABLE_SENSOR_2 || ENABLE_SENSOR_3 || ENABLE_SENSOR_4||ENABLE_SENSOR_5||ENABLE_SENSOR_6|| ENABLE_LSM9DS0 ||ENABLE_DS3231 || ENABLE_INA219 ||ENABLE_SEN0186 )
	Serial.println("NO SENSOR: ");
#endif
#if ENABLE_AM2315
	Serial.print("SENSOR AM2315: "); Serial.println(ENABLE_AM2315);
#endif
#if ENABLE_BME280
	Serial.print("SENSOR BME280: "); Serial.println(ENABLE_BME280);
#endif
#if ENABLE_OPCN3 
	Serial.print("SENSOR OPCN3: "); Serial.println(ENABLE_OPCN3);
#endif
#if ENABLE_SENSOR_1 || ENABLE_SENSOR_2
	Serial.print("ADS1115_1"); Serial.println(ENABLE_SENSOR_1 || ENABLE_SENSOR_2);
#endif
#if ENABLE_SENSOR_3 || ENABLE_SENSOR_4
	Serial.print("ADS1115_2"); Serial.println(ENABLE_SENSOR_3 || ENABLE_SENSOR_4);
#endif
#if ENABLE_SENSOR_5 || ENABLE_SENSOR_6
	Serial.print("ADS1115_3"); Serial.println(ENABLE_SENSOR_5 || ENABLE_SENSOR_6);
#endif
#if ENABLE_SENSOR_1
	Serial.print("SENSOR 1"); Serial.println(ENABLE_SENSOR_1);
#endif
#if ENABLE_SENSOR_2
	Serial.print("SENSOR 2"); Serial.println(ENABLE_SENSOR_2);
#endif
#if ENABLE_SENSOR_3
	Serial.print("SENSOR 3"); Serial.println(ENABLE_SENSOR_3);
#endif
#if ENABLE_SENSOR_4
	Serial.print("SENSOR 4"); Serial.println(ENABLE_SENSOR_4);
#endif
#if ENABLE_SENSOR_5
	Serial.print("SENSOR 5"); Serial.println(ENABLE_SENSOR_5);
#endif
#if ENABLE_SENSOR_6
	Serial.print("SENSOR 6"); Serial.println(ENABLE_SENSOR_6);
#endif
#if ENABLE_LSM9DS0
	Serial.print("SENSOR LSM9DS0"); Serial.println(ENABLE_LSM9DS0);
#endif
#if ENABLE_DS3231
	Serial.print("RTC DS3231"); Serial.println(ENABLE_DS3231);
#endif
#if ENABLE_INA219
	Serial.print("INA219"); Serial.println(ENABLE_INA219);
#endif
#if ENABLE_SEN0186
	Serial.print("SEN0186"); Serial.println(ENABLE_SEN0186);
#endif
#endif

}

void ControlUnit::INA219Init()
{
#if ENABLE_INA219
	bool isEnd = false;
	unsigned long int start = millis();
	while (!isEnd)
	{
		if ((start > millis()) ? (millis() + (pow(2, 32) - 1) - start) : (millis() - start) > 10 * 1000)
		{
			isEnd = true;
			this->enableINA219 = false;
#if  ENABLE_DEBUG_MODE
			Serial.println("Failed to find INA219 chip");
#endif
			this->logger(LOGACT_error_init_INA219);
		}

		if (this->INA219.begin())
		{
			isEnd = true;
			this->enableINA219 = true;
#if  ENABLE_DEBUG_MODE
			Serial.println("DEBUG: INA219 begin successful");
#endif	
			this->logger(LOGACT_init_INA219);
		}
		else
		{
			isEnd = false;
			this->enableINA219 = false;
		}
	}
	return;
#else
	return;
#endif
}

bool ControlUnit::getINA219status()
{
#if ENABLE_INA219
	return this->enableINA219;
#else
	return false;
#endif
}

float ControlUnit::getBatteryCurrent()
{
#if ENABLE_INA219
	if (this->enableINA219)
	{
#if  ENABLE_DEBUG_MODE
		float temp = this->INA219.getCurrent_mA();
		Serial.println("DEBUG: INA219 current successful>>>>value: " + String(temp));
		return temp;
#else
		return this->INA219.getCurrent_mA();
#endif
		this->logger(LOGACT_get_bat_mA);
	}
	else return NAN;
#else
	return NAN;
#endif
}

float ControlUnit::getBatteryVoltage()
{
	this->logger(LOGACT_get_bat_V);
	return NAN;
}

void ControlUnit::BME280Init()
{
#if  ENABLE_BME280
	bool isEnd = false;
	unsigned long int start = millis();
	while (!isEnd)
	{
		if (this->BME280.begin())
		{
			isEnd = true;
			this->enableBME280 = true;
#if  ENABLE_DEBUG_MODE
			Serial.println("DEBUG: BME280 begin successful");
#endif
			this->logger(LOGACT_init_BME280);
		}
		else
		{
			isEnd = false;
			this->enableBME280 = false;
		}

		if ((start > millis()) ? (millis() + (pow(2, 32) - 1) - start) : (millis() - start) > 10 * 1000)
		{
			isEnd = true;
			this->enableBME280 = false;
#if  ENABLE_DEBUG_MODE
			Serial.println("ERROR  BME280: Could not find a valid BME280 sensor");
#endif  
			this->logger(LOGACT_error_init_BME280);
		}
	}

#endif
	return;
}

bool ControlUnit::getBME280status()
{
#if ENABLE_BME280
	return this->enableBME280;
#else
	return false;
#endif
}


float ControlUnit::BME280ReadTemperature()
{

#if ENABLE_BME280
	if (this->enableBME280)
	{
		float temp = 0;
		if(this->BME280.readTemperature(&temp))
		{
#if  ENABLE_DEBUG_MODE
			Serial.println("DEBUG: BME280 Temperature successful>>>>value: " + String(temp));
			Serial.println(temp);
#endif 
			this->logger(LOGACT_read_BME280_temp);
		}
		else
		{
#if  ENABLE_DEBUG_MODE
				Serial.println("DEBUG: BME280 Temperature error");
#endif
			temp=NAN;
			this->logger(LOGACT_error_read_BME280_temp);
		}
		return temp;
	}
	else
	{
		return NAN;
	}
#else
	return NAN;
#endif
}

float ControlUnit::BME280ReadHumidity() {
#if  ENABLE_BME280
	if (this->enableBME280)
	{
		float temp = 0; 	
		if(this->BME280.readHumidity(&temp))
		{
		#if ENABLE_DEBUG_MODE
			Serial.println("DEBUG: BME280 Humidity successful>>>>value: " + String(temp));
		#endif
			this->logger(LOGACT_read_BME280_hum);
		}
		else 
		{
		#if ENABLE_DEBUG_MODE
			Serial.println("DEBUG: BME280 Humidity error");
		#endif
			this->logger(LOGACT_error_read_BME280_hum);
			temp = NAN;
		}
		return temp;
	}
	else
	{
		return NAN;
	}
#else
	return NAN;
#endif
}

float ControlUnit::BME280ReadPressure()
{
#if  ENABLE_BME280
	if (this->enableBME280)
	{
		float temp = 0;
		if(this->BME280.readPressure(&temp))
		{
			temp/=100.0;
			#if ENABLE_DEBUG_MODE
			Serial.println("DEBUG: BME280 Pressure successful>>>>value: " + String(temp));
			#endif
			this->logger(LOGACT_read_BME280_pressure);
		}
		else 
		{
			#if ENABLE_DEBUG_MODE
			Serial.println("DEBUG: BME280 Pressure error");
			#endif
			this->logger(LOGACT_error_read_BME280_pressure);
			temp = NAN;
		}
		return temp;
	}
	else
	{
		return NAN;
	}
#else
	return NAN;
#endif
}
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

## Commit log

2020-04-01 Add files via upload
    main R script for the analysis of Temperature data
    [MRG_2017_2018.csv, MRGtemperaturetypicalyear.csv, P_Valles_2010_2020.csv]
2020-04-01 Add files via upload
    lavoro sulle variabili meteo quasi completo. manca la direzione del vento
    [MRGatmosphericpressuretypicalyear.csv, MRGrelativehumiditytypicalyear.csv, MRGsolarradiationtypicalyear.csv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]
2020-10-10 Create msg.txt
    Questo è il file contenente il "messaggio tipo" di un nodo. La descrizione del file, da Baseggio e Granziol, è la seguente:
    Ogni pacchetto comunicato in seriale dal gateway al raspberry cominica con "sp"
    e terminata con "ep". Dopo "sp" è presente un header composto da, in ordine di
    successione, l'indirizzo dell'endnode che ha inviato il pacchetto, il numero di
    letture, il voltaggio della battiera, la corrente della batteria, il S/N di
    LoRa e RSSI di LoRa. Finito l'header ci sono le letture, in numero indicato
    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
2020-10-10 Create sendmsg.sh
    Questo programma serve per mandare il messaggio "msg.txt" attraverso la porta seriale di una macchina linux (ubuntu). La macchina con cui sono stati fatti i test è un ubuntu 18.04 con un adattatore s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
2020-10-10 Create serial_read.py
    Questo programma, eseguito su raspberry pi (nei test RP3b+) legge continuamente dalla porta seriale e stampa su terminale il messaggio in arrivo. Questo programma è utile per verificare il funzioname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
2020-10-10 Create serial_save_base.py
    Questo programma serve salvare il messaggio in arrivo sulla porta seriale su file "dataFile.txt"
2020-10-10 Create serial_parse_gateway.py
    Versione in evoluzione del programma da eseguire sul raspberry pi collegato in seriale al gateway. Lo scopo del programma è leggere e bufferizzare il messaggio seriale inviato dal gateway. Successiva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
2020-10-10 Create 20201010MrgRosyGatewayAll.txt
    Esempio di file di dati giornaliero.

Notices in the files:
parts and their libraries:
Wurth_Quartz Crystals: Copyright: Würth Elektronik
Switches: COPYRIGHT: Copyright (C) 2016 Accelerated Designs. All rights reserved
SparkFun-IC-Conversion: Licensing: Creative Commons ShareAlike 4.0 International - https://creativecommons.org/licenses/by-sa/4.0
